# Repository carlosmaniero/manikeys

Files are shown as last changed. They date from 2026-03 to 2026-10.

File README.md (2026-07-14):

# Manikeys Keyboard

Manikeys

[3D Model (STL)](https://raw.githubusercontent.com/carlosmaniero/manikey/assets/main.stl)

## Views

| | | |
| :---: | :---: | :---: |
| 0° | 45° | 90° |
| 135° | 180° | 225° |
| 270° | 315° | Top |
| Side | Side Inv | Back |

This project uses standard Python with [Manifold3D](https://github.com/elalish/manifold) and [PyVista](https://pyvista.org) to design a custom 3D-printable keyboard based on spherical projections.

## Requirements

- **F3D**: Required for the `render` step (generating PNGs).

## Development

- `make build`: Generate the STL and 3MF files for `src/main.py`.
- `make render`: Generate PNG renderings (Front, Back, Top, Side) for `src/main.py`.
- `make build/ANY_FILE.stl`: Generate STL file for `src/ANY_FILE.py`.
- `make build/ANY_FILE.3mf`: Generate 3MF file for `src/ANY_FILE.py`.
- `make build/ANY_FILE.png`: Generate PNG rendering for `src/ANY_FILE.py`.
- `make test`: Run tests.
- `make lint`: Check code quality.
- `make viewer`: Start the web-based 3D viewer.

## 3D Viewer

The project includes a web-based 3D viewer to visualize, build, and measure your keyboard models.

### Features
- **Live Preview**: See your models as you develop.
- **Auto-Rebuild**: Enable "Watch for Changes" to automatically rebuild the STL and reload the viewer when you save a Python file.
- **Measurement Tool**: Measure distances between vertices with snapping (shortcut: `M`).
- **Reference Model**: Load a second model as a transparent reference to compare changes.
- **Build Control**: Trigger builds directly from the browser.

### Running the Viewer

1.  **Install dependencies**:
    ```bash
    uv sync --group dev
    ```

2.  **Start the viewer**:
    ```bash
    make viewer
    ```

3.  **Open your browser**:
    Navigate to `http://localhost:6333`

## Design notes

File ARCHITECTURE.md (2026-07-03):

# Manikeys Architecture

Manikeys is a modular, model-driven CAD system for designing
ergonomic keyboards. It combines the power of NumPy/PyVista for
complex surface generation with PythonSCAD for final assembly and
CSG operations.

## High-Level Overview

The system follows a pipeline where data models drive the generation
of individual geometry components, which are then simplified and
assembled into the final 3D model.

```mermaid
graph TD
    subgraph "Data & Models"
        P[Parameters] --> L[Layout]
        P --> BM[BodyModel]
        SP[SphereProjection] --> L
    end

    subgraph "CAD Generation (CAD Layer)"
        L --> CG[CapGridCAD]
        BM --> BC[BodyCAD]
        BC -- "PyVista" --> BSTL[body.stl]
        CG -- "OpenSCAD" --> CGSTL[cap_grid.stl]
    end

    subgraph "Assembly & Post-processing"
        BSTL --> S[simplify.py]
        S --> BSTL_OPT[body.stl optimized]
        BSTL_OPT --> M[main.py]
        CGSTL --> M
        M -- "OpenSCAD" --> MSTL[main.stl]
    end

    subgraph "Visualization"
        MSTL --> F3D[f3d]
        F3D --> PNG[renders]
    end
```

## Core Components

### 1. Data Models (`src/models/` & `src/data/`)
The "brain" of the project. Everything is parametric.
- **Parameters**: Defines physical constants (cap size, gap, wall
  thickness, fillet radius).
- **Layout**: Calculates the 3D position and rotation of every key.
  It uses **Spherical Projections** to ensure keys are ergonomically
  oriented towards a central point.
- **BodyModel**: A mathematical representation of the keyboard's
  shell. It uses smooth interpolation functions to define the top
  surface $z = f(x, y)$, including complex areas like the thumb
  section.

### 2. CAD Objects (`src/cad/`)
Wrappers around geometry kernels that transform models into 3D
files.
- **`Object[T]`**: An abstract base class providing a common
  interface for `assemble()`, `save()`, and `show()`.
- **`ManifoldObject` (Manifold3D)**: Used for precise, fast boolean operations
  and geometry generation. It produces `manifold3d.Manifold` objects.
- **`VistaObject` (PyVista)**: Used for the keyboard body. It
  generates a dense mesh of points using NumPy meshgrids, which is
  ideal for smooth, organic surfaces.
- **`OSCObject` (PythonSCAD)**: Used for components that benefit
  from CSG (unions, differences) or for the final assembly.

### 3. Dependency Injection (`src/context.py`)
The project uses the `injector` library to manage dependencies. This
allows CAD classes to receive their required models (like
`BodyModel` or `Layout`) without knowing how they were constructed
or projected.

### 4. Build System (`Makefile`)
The build process is orchestrated by a `Makefile` to handle the multi-tool pipeline:
1.  **Component Generation**: Individual scripts generate STL files
    for the body, keycaps, and grids.
2.  **Mesh Optimization**: Complex meshes (like the body) are
    generated with high resolution and then simplified using
    `meshlib` (`simplify.py`) to reduce file size while maintaining
    detail.
3.  **Final Assembly**: `src/main.py` loads the optimized STL
    components and performs the final boolean operations (e.g.,
    subtracting keycap holes from the body).

## Design Decisions

- **Hybrid Geometry Kernel**: Using PyVista/NumPy for the body
  allows for complex mathematical surfaces that are difficult to
  define in pure CSG. PythonSCAD is then used for what it does best:
  assembling parts and final boolean operations.
- **Parametric Everything**: By decoupling the projection logic
  (`src/models/projection.py`) from the layout, the keyboard can be
  easily adjusted for different hand sizes or ergonomic preferences
  by changing a few parameters.
- **Component MVC Pattern**: Each individual component (like an OLED screen or RJ45 connector) strictly separates data, logic, and geometry:
  1. **Parameters** (`parameters.py`): A dataclass defining raw physical dimensions.
  2. **Model** (`model.py`): Injects parameters and calculates spatial coordinates, bounding boxes, and offsets.
  3. **CAD** (`cad/*.py`): Injects the model and blindly executes the boolean CSG operations based on the model's coordinates using `ManifoldObject`.
- **Off-screen Assembly**: The final assembly (`main.py`) loads STLs
  generated in previous steps. This speeds up the build process by
  allowing parallel generation of components and avoids
  re-calculating complex body surfaces during final assembly.

## Technology Stack

- **Manifold3D**: A fast, robust geometry kernel used directly and via PythonSCAD for exact boolean operations and mesh generation.
- **PythonSCAD**: The primary engine for OpenSCAD-based 3D
  generation, utilizing the Manifold backend.
- **PyVista / NumPy**: For point-cloud and mesh generation of
  organic surfaces.
- **MeshLib (mrmeshpy)**: For mesh simplification and optimization.
- **F3D**: For high-quality automated rendering of the final model.
- **Injector**: For clean dependency management between data models
  and CAD logic.

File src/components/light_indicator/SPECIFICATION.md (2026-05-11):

# Light Indicator Specification

The light indicator component is designed to work with an Arduino Nano and WS2812B chips.

## Components

- **Controller**: Arduino Nano
- **LEDs**: [WS2812B Chips](https://pt.aliexpress.com/item/4000879938744.html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)

## Wiring Diagram

The indicator soldering pins should be connected as follows:

| Indicator Pin | Arduino Nano Pin | Notes |
| :--- | :--- | :--- |
| **VCC** | 5V | |
| **GND** | Ground | |
| **DIN** | D6 | Data In |
| **SDA** | A4 | I2C Data |
| **SCL** | A5 | I2C Clock |

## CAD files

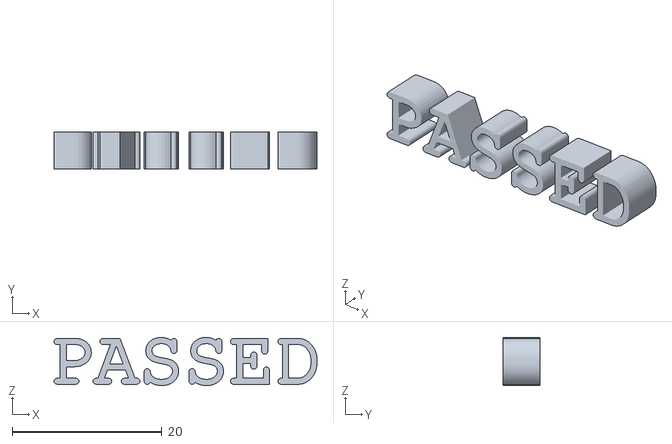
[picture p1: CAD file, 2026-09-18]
dist/test_passed.stl
35.1 x 5.00 x 6.42

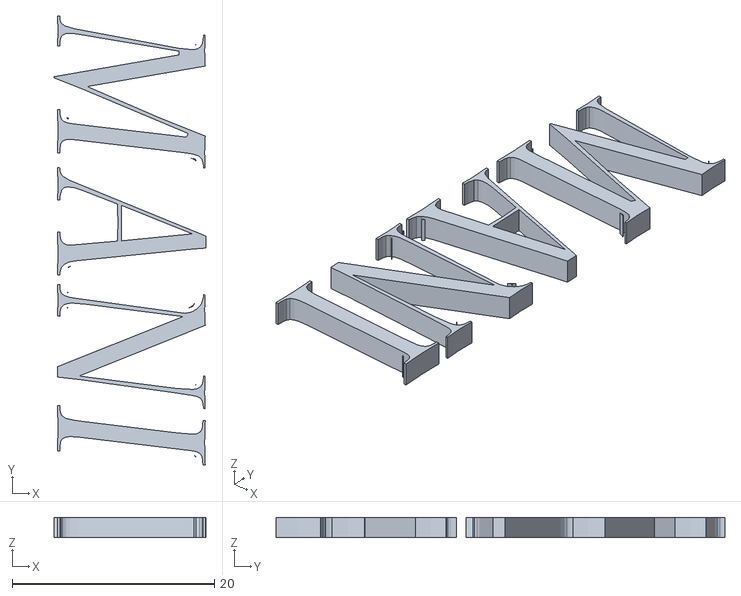
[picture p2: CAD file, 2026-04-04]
dist/mani-logo.stl
15.0 x 44.4 x 2.00

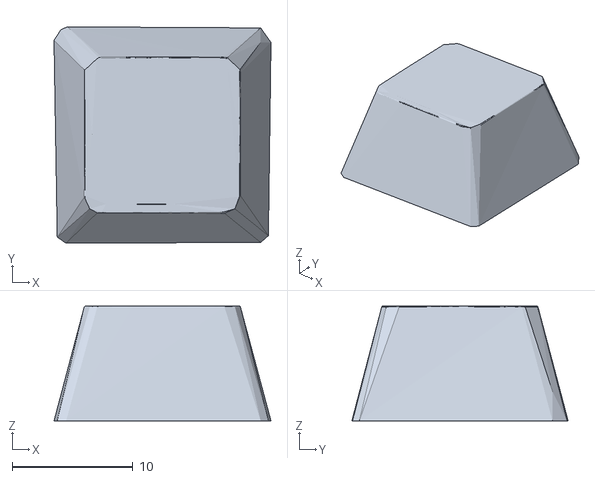
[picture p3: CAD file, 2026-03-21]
dist/Simple-CherryMX-Keycap.stl
18.0 x 17.9 x 9.50

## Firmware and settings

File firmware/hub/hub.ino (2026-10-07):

#include <Arduino.h>
#include <comm_spi.h>
#include <Keyboard.h>
#include <Adafruit_NeoPixel.h>
#include <msg_ctrl.h>
#include <key_matrix.h>

const uint8_t SLAVE_PIN = 9;

#define LED_PIN 10
#define NUM_LEDS 3
Adafruit_NeoPixel pixels(NUM_LEDS, LED_PIN, NEO_GRB + NEO_KHZ800);

enum LedColor { LED_YELLOW, LED_GREEN, LED_RED };
static LedColor current_led_color = (LedColor)-1;

void set_led_color(LedColor color) {
  if (current_led_color == color) return;
  current_led_color = color;

  uint8_t r = 0, g = 0, b = 0;
  if (color == LED_YELLOW) {
    r = 150; g = 100; b = 0;
  } else if (color == LED_GREEN) {
    r = 0; g = 150; b = 0;
  } else if (color == LED_RED) {
    r = 150; g = 0; b = 0;
  }

  for (uint8_t i = 0; i < NUM_LEDS; i++) {
    pixels.setPixelColor(i, pixels.Color(r, g, b));
  }
  pixels.show();
}

const uint8_t key_map[5][7] = {
  {KEY_BACKSPACE, '5', '4', '3', '2', '1', KEY_ESC},
  {KEY_LEFT_ALT, 't', 'r', 'e', 'w', 'q', KEY_TAB},
  {KEY_LEFT_SHIFT, 'g', 'f', 'd', 's', 'a', ' '},
  {KEY_LEFT_CTRL, 'b', 'v', 'c', 'x', 'z', '-'},
  {KEY_RETURN, KEY_RIGHT_ARROW, KEY_UP_ARROW, KEY_DOWN_ARROW, KEY_LEFT_ARROW, '-', '-'}
};

const uint8_t LEFT_MATRIX_ROWS = 5;
const uint8_t LEFT_MATRIX_COLS = 5;

uint8_t left_matrix[LEFT_MATRIX_ROWS];

static unsigned long last_heard_from_slave = 0;

void setup() {
  pixels.begin();
  set_led_color(LED_YELLOW);

  Serial.begin(9600);

  msg_ctrl_init();
  key_matrix_init(left_matrix, LEFT_MATRIX_ROWS);

  Serial.println("Hub initialized. Setting up SPI...");

  comm_spi_set_master();
  comm_spi_add_slave(SLAVE_PIN);

  delay(5000);
  Keyboard.begin();
  set_led_color(LED_GREEN);
  last_heard_from_slave = millis();
}

void loop() {
  msg_t *resp = NULL;
  static bool is_alive = false;

  comm_spi_start_transaction(SLAVE_PIN);

  for (uint8_t i = 0; i < 32; i++) {
    msg_ctrl_tick();
    resp = msg_ctrl_consume_response();

    if (resp != NULL) {
      break;
    }

    delayMicroseconds(30);
  }

  comm_spi_end_transaction(SLAVE_PIN);

  if (resp == NULL) {
    msg_t *rx_msg = queue_get_last(&msg_ctrl.rx);
    if (rx_msg->_cursor > 0) {
      msg_reset(rx_msg);
    }
    if (millis() - last_heard_from_slave > 2000) {
      set_led_color(LED_RED);
    }
    if (is_alive) {
      Serial.println("Error: Slave disconnected!");
      is_alive = false;
    }
  } else {
    last_heard_from_slave = millis();
    set_led_color(LED_GREEN);
    if (!is_alive) {
      Serial.println("Slave on pin 9 is ALIVE!");
      is_alive = true;
    }

    if (resp->kind == MSG_KIND_KEYS) {
      bool any_pressed = false;
      uint8_t diff[LEFT_MATRIX_ROWS];

      key_matrix_diff(left_matrix, resp->buffer, diff, LEFT_MATRIX_ROWS);

      for (uint8_t r = 0; r < resp->size; r++) {
        for (uint8_t c = 0; c < 7; c++) {
          if (key_matrix_is_active(diff + r, c)) {
            if (key_matrix_is_active(resp->buffer + r, c)) {
              key_matrix_set_pressed(left_matrix + r, c);
              uint8_t key = key_map[r][c];
              if (key != '-') {
                Keyboard.press(key);
              }
            } else {
              key_matrix_set_released(left_matrix + r, c);
              uint8_t key = key_map[r][c];
              if (key != '-') {
                Keyboard.release(key);
              }
            }
          }
        }
      }
    } else if (resp->kind != MSG_KIND_HEARTBEAT) {
      Serial.print("Received message of kind: 0x");
      Serial.println(resp->kind, HEX);
    }
  }

  delay(10);
}

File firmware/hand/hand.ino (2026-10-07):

#include <Arduino.h>
#include <Wire.h>
#include <Adafruit_GFX.h>
#include <Adafruit_SSD1306.h>

#define SCREEN_WIDTH 128
#define SCREEN_HEIGHT 64
#define OLED_RESET -1
#define SCREEN_ADDRESS 0x3C

Adafruit_SSD1306 display(SCREEN_WIDTH, SCREEN_HEIGHT, &Wire, OLED_RESET);

const uint8_t KEY_PINS[] = {3, 4, 5, 6};
const uint8_t NUM_KEYS = 4;
const char* KEY_NAMES[] = {"D3", "D4", "D5", "D6"};

bool lastState[NUM_KEYS];

void displayMessage(const char* line1, const char* line2) {
  display.clearDisplay();
  display.setTextSize(2);
  display.setTextColor(SSD1306_WHITE);
  display.setCursor(0, 10);
  display.println(line1);
  if (line2 != NULL) {
    display.setCursor(0, 35);
    display.println(line2);
  }
  display.display();
}

void setup() {
  for (uint8_t i = 0; i < NUM_KEYS; i++) {
    pinMode(KEY_PINS[i], INPUT_PULLUP);
    lastState[i] = digitalRead(KEY_PINS[i]);
  }

  if (!display.begin(SSD1306_SWITCHCAPVCC, SCREEN_ADDRESS)) {
    for (;;);
  }

  displayMessage("Hello", "World");
}

void loop() {
  for (uint8_t i = 0; i < NUM_KEYS; i++) {
    bool currentState = digitalRead(KEY_PINS[i]);
    if (lastState[i] == HIGH && currentState == LOW) {
      displayMessage("Pressed:", KEY_NAMES[i]);
    }
    lastState[i] = currentState;
  }
  delay(10);
}

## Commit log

2026-02-23 move cad files to a cad directory
2026-03-15 split the grid and the cap hole
2026-03-21 add caps top to have a better preview
    [Simple-CherryMX-Keycap.stl]
2026-03-22 create dividers on the cap hole
2026-03-22 move the hard coded cable radius variable to a parameter
2026-03-23 add the cap socket connector
    [socket_adapter.scad]
2026-03-27 translate the scad to python code
    [socket_adapter.scad]
2026-03-27 add the socket placement
2026-03-29 splits the keyboard into small printable parts
2026-03-31 add cable path to join the keyboard.
2026-04-02 create a basic structure for screw the bottom
2026-04-02 creates a mask for the screws
2026-04-02 add the screw holes
2026-04-04 add the mani logo at the keyboard
    [mani-logo.stl]
2026-04-04 update the log to have only the name
    [mani-logo.stl]
2026-04-04 keep camera positioning when reload the object
2026-04-04 add buttons to control the view
2026-04-07 add rj11 connectors
2026-04-07 adds the rj11 conector to the body
    There are a design issue the connector makes the inner section stuck in
    the body.
2026-04-09 make room to the socket.
2026-04-21 add the usbc connector placement
2026-04-25 add pogo pin adapter
2026-04-26 adds magnet to connect the parts
2026-04-26 make rj11 connector to stick to the top
    This is to increase the object structure.
2026-04-26 also make the usbc connector to join the top layer
2026-04-26 move screw mask to the shell
2026-04-27 redistribute magnets
    now we have no longer the issue of having them in a curved surface
2026-05-03 create a tab mechanism to hold the rj11 connector
2026-05-03 fix the socket shell if the new rj11
2026-05-03 fix missing rj11 in the main.stl
2026-05-18 adds the led indicator to the body
2026-06-24 add a oled 096 screen housing
2026-06-25 fixes issues in the cable path
2026-06-28 add extra magnects in the y axis
2026-07-01 remove unused model and build show cad files in the viewer
2026-07-01 refactor: move screw parameters to its own file
2026-07-01 organize switch files and rename from caps to switch
2026-07-01 refactor: socket_adapter => hot_swap
2026-07-01 refactor: fix the hot swap hole
2026-07-01 refactor: socket_adapter => socket/mount
2026-07-01 refactor: organize screw structure
2026-07-01 refactor: move full keyboard to assembly
2026-07-01 refactor: move the pogo connectors to a module
2026-07-01 refactor: move the magnet snap to the new structure
2026-07-04 add the arduino pro micro case
2026-07-05 add arduino nano case
2026-07-06 add the bottom plate
2026-07-10 basic initial structure for the arduinos
2026-07-11 Add spi implementation
2026-07-11 use SPI interruptors to process messages
2026-07-12 fix master to communicate with the child
    [hub.ino, matrix_scaner.ino]
2026-07-12 send/retrieve the entire message under the interruptor
2026-07-13 replace switch hole decorator from openscad to manifold
2026-07-15 split father/child spi impl
2026-07-15 avoid having an extra empty message every cycle
    [comm_spi.cpp]
2026-07-18 increase the height of the keyboard
    The bottom screwed part will be hidden
2026-07-18 make screws placement of the body inside the object
2026-07-18 add an structural wall for the screws
    It makes the shell stronger
2026-07-18 fix hand section shell
    - add a better housing for oled
    - add decorators to the hot swap
2026-07-18 fix base plate
2026-07-18 make the base plate to fit at the bottom of the body
2026-07-18 create a new version of the cable path
2026-07-20 wip on cable path
2026-07-22 add a location for the cable to be organized
2026-07-22 add row cable placement
2026-07-22 create a pin head placement
2026-07-22 make the pin hole to be placed upside down
2026-07-25 add a cli to create new cad files
2026-07-25 deps.stl are never optional
2026-07-27 create basic version of pin header
2026-09-12 add a divider y in the base plate
2026-09-13 make sure the screw placement matches the bottom_plate
2026-09-14 adjust the bitola of the wire hole
2026-09-15 make sure there is room to pass the wires
2026-09-15 use a single snap connector
2026-09-16 add some pads to screw the arduinos
2026-09-16 add some m2 screw holes
2026-09-16 introduce a pcb frame
2026-09-16 add the support for the PCBs
2026-09-16 add some gap in between arduinos
2026-09-18 create a cad file to represent the test to be easier to troubleshoot
    [test_passed.stl]
2026-09-19 add a rj45 panel mount
2026-09-19 add screw head placement
2026-09-19 remove arduino from base plate
2026-09-19 fix pin issue
2026-09-21 make the pcb placement structure stronger
2026-09-26 remove soldering location
2026-09-26 improve switch
2026-09-26 create a pcb shell decorator
2026-09-26 fix the size of the pcb
2026-09-26 fix the pcb size
2026-09-26 add screw holes
2026-09-26 fix the top screws
2026-09-27 extract the screws to another file
2026-09-27 apply the screw holes to the keyboard
2026-09-27 add an extra cutout space in the pcb decorator
2026-09-27 add some spacing for the screws
2026-09-27 add a extra thickness to the pcb placement
2026-09-27 add a guide for the pcb to fit in
2026-09-27 increase the pocket size of the cable matrix
2026-09-27 add the screw placement in the full keyboard
2026-09-27 fix pcb mount to be placed direct on the full keyboard
2026-09-28 increase the pcb thin
2026-09-28 start the third version of the hot swap socket
2026-09-28 add the led placement in the v3
2026-09-28 add the diode
2026-09-30 increase the screw pocket hole
2026-10-02 add a wire strip holder
2026-10-02 create the pcb of hand section
2026-10-02 add screw holes in the pcb of the hand
2026-10-02 add the pcb of the hand part
2026-10-02 add the tabs for the pcbs
2026-10-02 add a divider in x to the base plate
2026-10-02 increase the clearance of the base plate
2026-10-06 add the hand base plate
2026-10-07 add an offset to avoid the hole pass through
